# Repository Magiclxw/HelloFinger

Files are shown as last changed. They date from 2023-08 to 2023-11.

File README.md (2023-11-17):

# HelloFinger
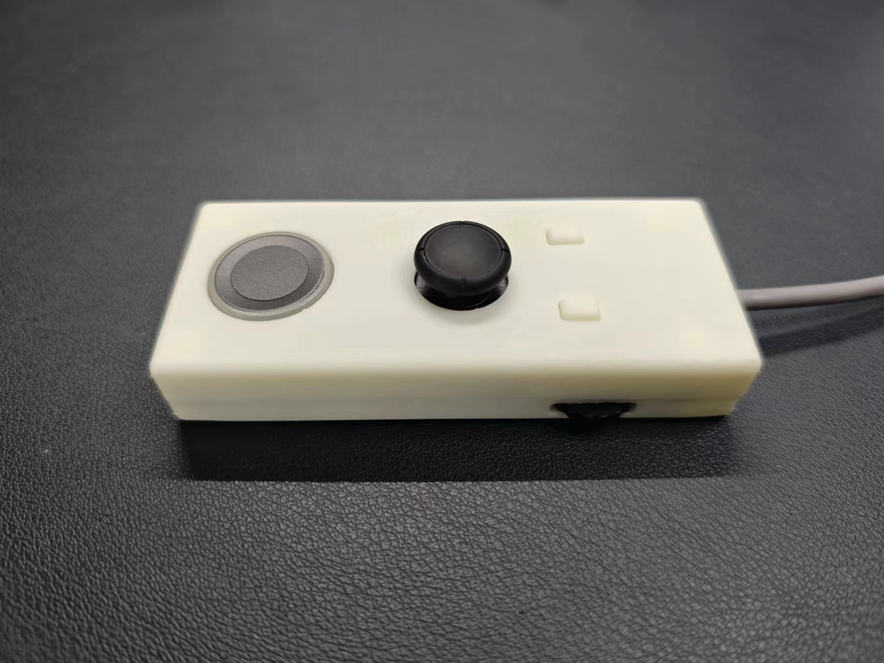
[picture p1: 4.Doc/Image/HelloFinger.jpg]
HelloFinger

## 关于本项目：
本项目通过操作单个模块，实现与Windows系统的HID通信，配合上位机实现电脑开机、电脑解锁、鼠标控制、快捷键、多任务、AI对话等功能。

## 项目相关功能：  
  1. AI 对话：接入通义千问API，可进行对话、问答；
  2. 一键开机：HelloFinger具有物理开机按键，按下按键即可实现电脑开机；
  3. 指纹解锁：无需输入密码，验证指纹即可实现电脑解锁；
  4. 自动输入账号密码：在需要输入账号密码的地方通过录入指纹即可自动输入和登录；
  5. 快捷键：可自定义配置快捷键，配置完成后录入指纹即可输入快捷键；
  6. 快捷启动多任务：可自由添加需要启动的程序，配置完成后录入指纹即可一键开启所有程序；
  7. 鼠标：HelloFinger具有鼠标左键、右键、滚轮的功能；
  8. Action：HelloFinger具有一个物理Action按键，用户可以自定义其功能；
  9. RGB灯效：HelloFinger具有6颗RGB灯，可以通过上位机配置其灯效；

## 开发平台：
-**外壳设计**：SolidWorks  
-**原理图、PCB设计**：立创eda  
-**固件开发**：Keil5  
-**上位机开发**：Qt  

## 设计原理
HelloFinger使用一颗STM32F103作为主控通过串口与CH9329芯片通信,CH9329通过HID接口与Windows系统交互；交互方式分为两类，一类直接操作Windows系统，一类以自定义数据包方式与Windows系统进行数据传输。上位机通过HID接口收发自定义数据包，进而实现自定义的交互功能。
在整个系统中，CH9329芯片作为处理器和上位机通信的桥梁，硬件外设产生的各种操作(如编码器拨动、摇杆移动、指纹识别验证等)经过处理后都会通过CH9329传输到电脑，同时，上位机的各种操作也会通过CH9329以指令的方式传输给处理器。

## 开发环境
  1. Qt
     1. 版本：V5.12.12
     2. 编译环境: MinGW 32-bit
     3. 链接库
        1. [全局鼠标键盘监听库](https://github.com/mahuifa/QtGlobalEvent)
        2. [HID通信库](https://github.com/libusb/hidapi)
  2. Keil 5
     1. 版本:5.26.2
     2. 编译器:5.06
     3. 软件包:Keil.STM32F1xx_DFP.2.1.0

## 目录结构
  1. Hardware:硬件文件夹，包含与PCB相关文件；
  2. Firmware:固件文件夹，包含STM32开发相关工程，**bootloader功能尚未实现**；
  3. Software:上位机文件夹，包含上位机工程及编译文件；
  4. Doc:文档文件夹，包含datasheet以及项目相关文档；
  5. Model:模型文件夹：包含3D打印文件；
  6. Tools：工具文件夹：包含硬件外设的测试工具；

## 原理图
  1. 连接器  
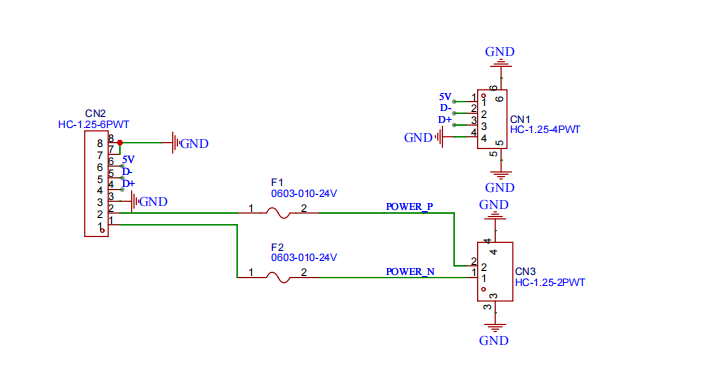
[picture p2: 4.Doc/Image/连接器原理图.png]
连接器
  
  2. 主板  
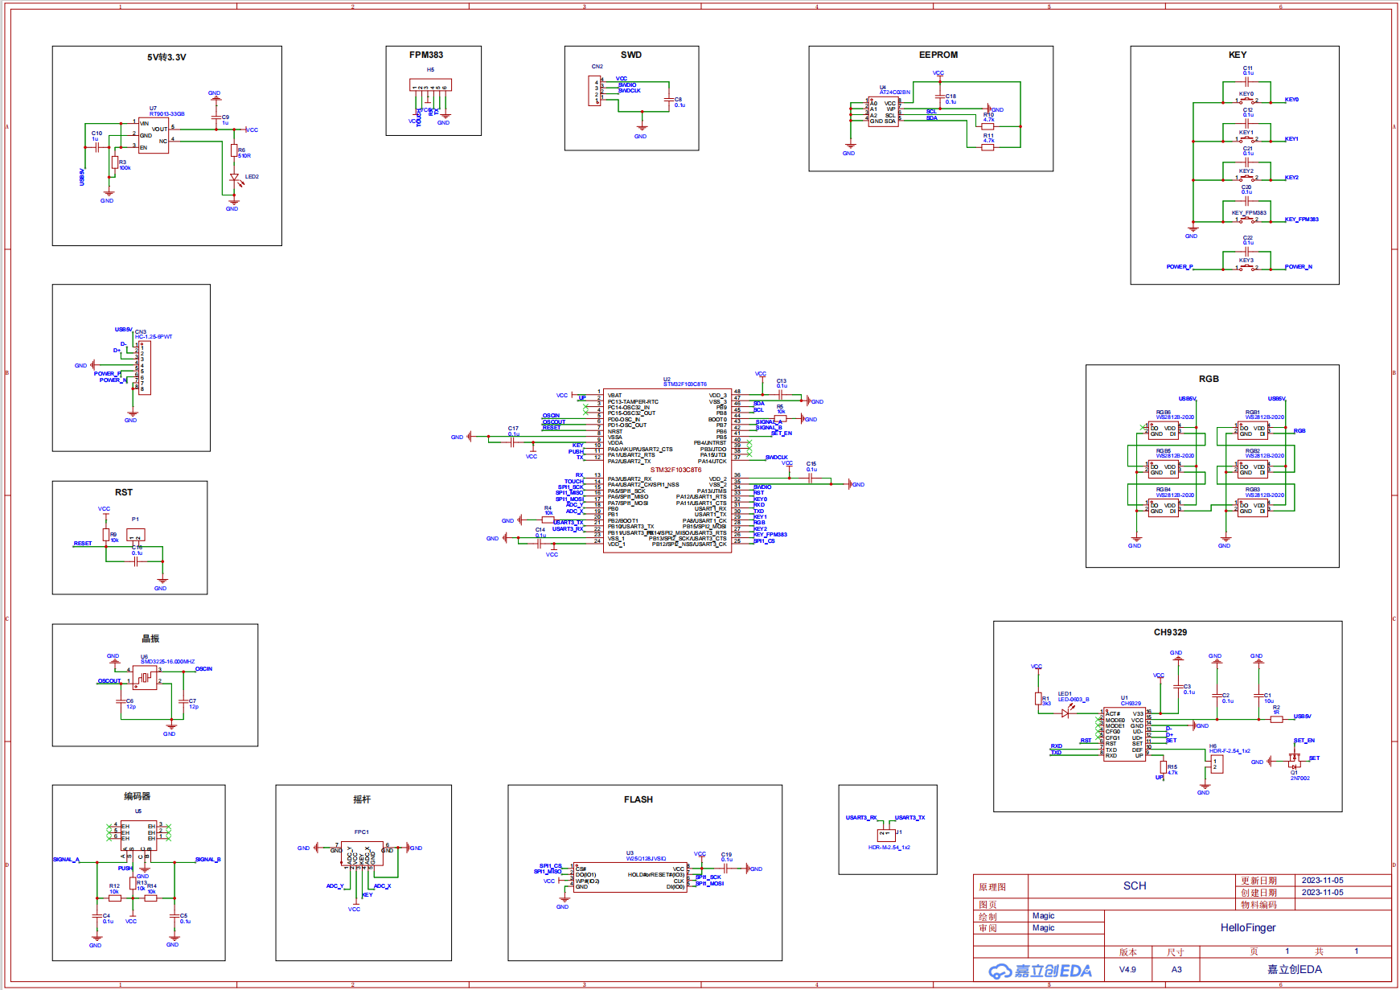
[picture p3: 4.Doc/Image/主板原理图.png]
主板
  

## PCB说明
本项目需要2个PCB板，分别是主板和连接器板，其中连接器板不是必须的，如果不需要连接电脑的物理开机键，就可以舍弃掉连接器板。
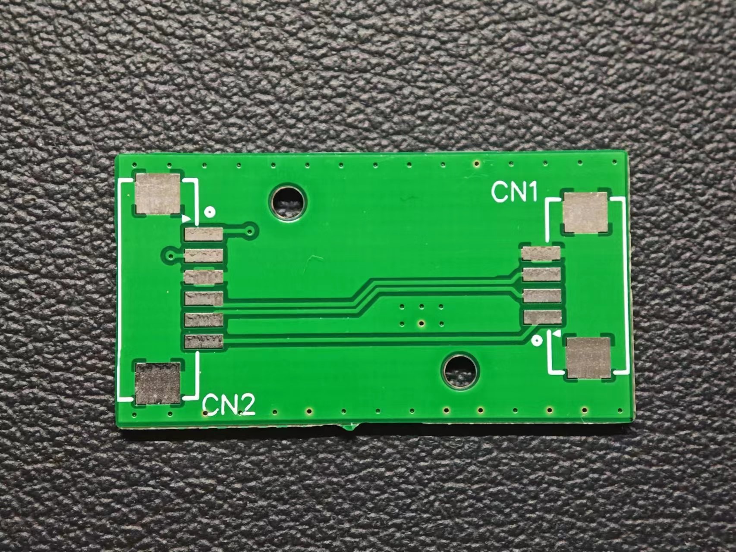
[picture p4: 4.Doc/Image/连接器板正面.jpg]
连接器板正面
  1. 连接器板正面
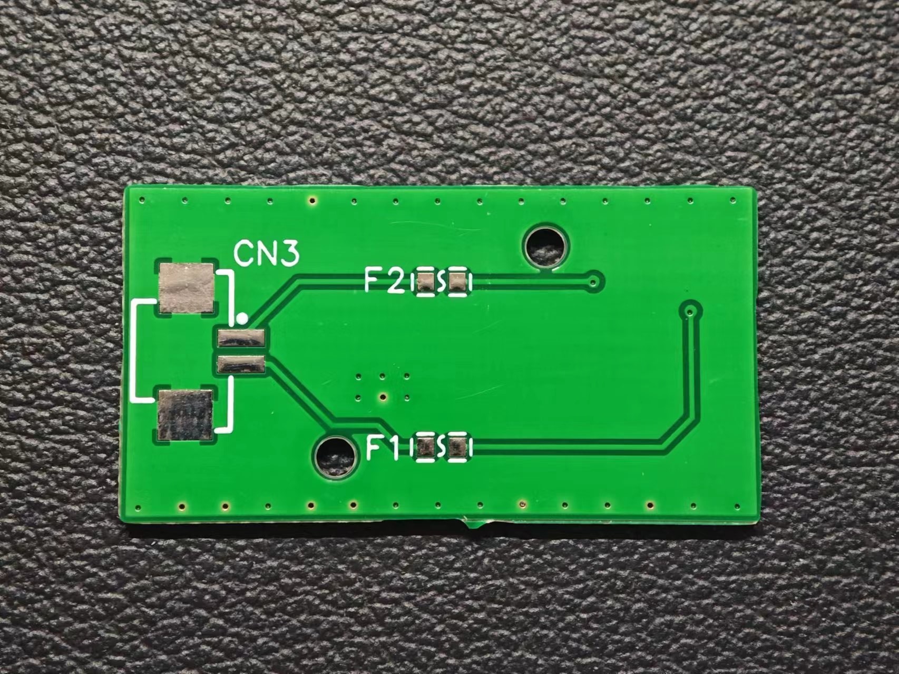
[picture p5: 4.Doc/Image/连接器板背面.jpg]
连接器板背面
  2. 连接器板背面
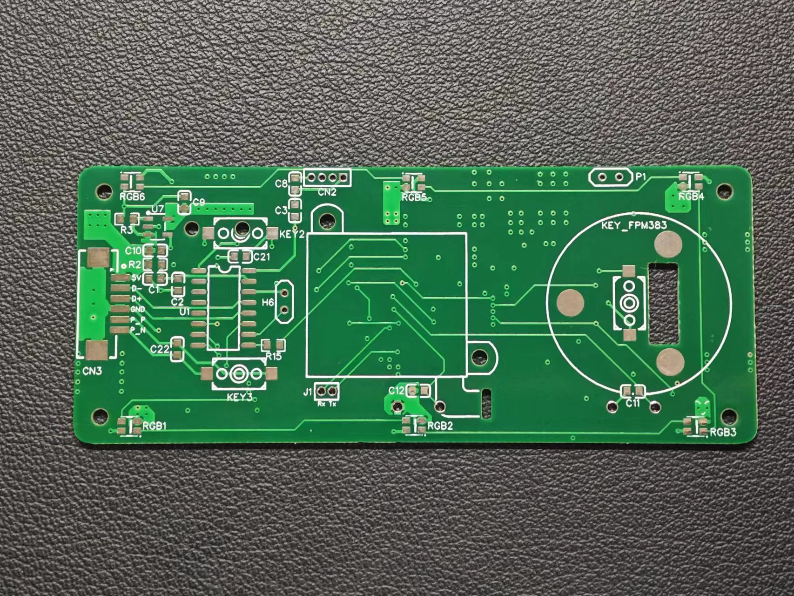
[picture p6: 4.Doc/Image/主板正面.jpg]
主板正面
  3. 主板正面
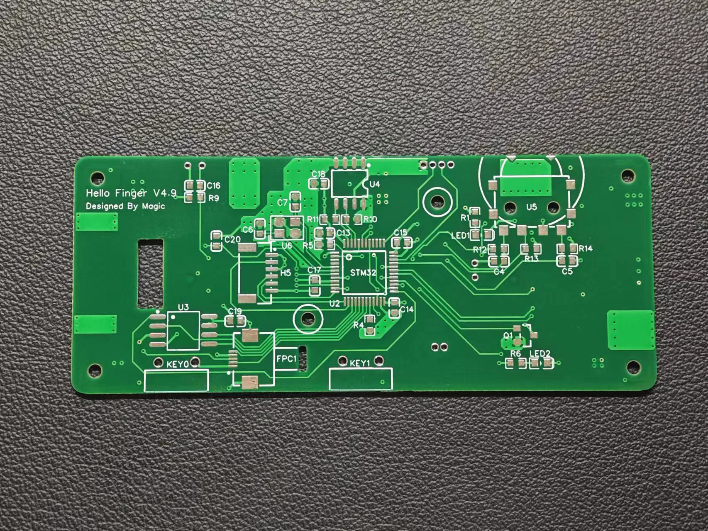
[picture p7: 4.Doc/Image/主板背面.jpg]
主板背面
  4. 主板背面
PCB采用4层板，电容电阻封装采用0603，整体含有3个非标准封装，分别是JoyStick摇杆、FPM383C指纹识别模块以及弯角微动。
PCB焊接时需要遵循一定的焊接步骤，具体的步骤见[焊接指南](https://github.com/Magiclxw/HelloFinger/blob/main/4.Doc/HelloFinger%E7%84%8A%E6%8E%A5%E6%8C%87%E5%8D%97V1.0.pdf)

## 3D结构件
HelloFinger一共有8个结构件，分别是[连接器上壳](https://github.com/Magiclxw/HelloFinger/blob/main/5.Model/%E8%BF%9E%E6%8E%A5%E5%99%A8%E4%B8%8A%E5%A3%B3..STL)、[连接器下壳](https://github.com/Magiclxw/HelloFinger/blob/main/5.Model/%E8%BF%9E%E6%8E%A5%E5%99%A8%E4%B8%8B%E5%A3%B3.STL)、[主板上壳](https://github.com/Magiclxw/HelloFinger/blob/main/5.Model/%E4%B8%8A%E5%A3%B3.STL)、[主板下壳](https://github.com/Magiclxw/HelloFinger/blob/main/5.Model/%E4%B8%8B%E5%A3%B3.STL)、[上按钮*2](https://github.com/Magiclxw/HelloFinger/blob/main/5.Model/%E4%B8%8A%E6%8C%89%E9%92%AE.STL)、[侧键*2](https://github.com/Magiclxw/HelloFinger/blob/main/5.Model/%E4%BE%A7%E9%94%AE.STL)。
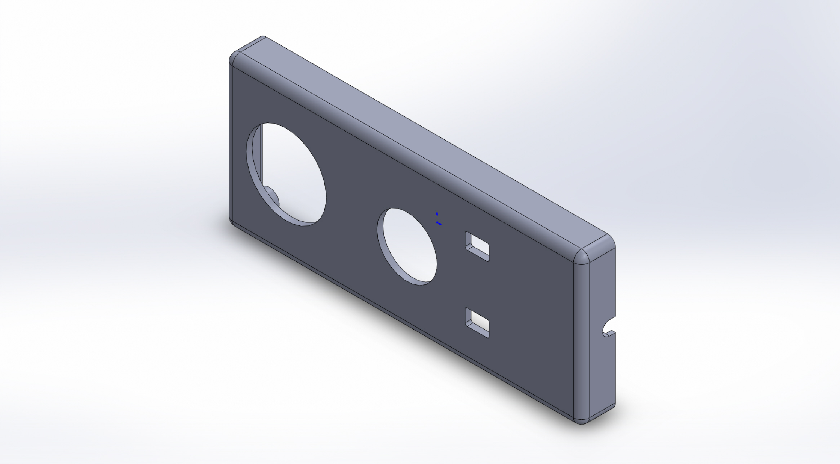
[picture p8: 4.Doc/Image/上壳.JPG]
上壳
  1. 上壳
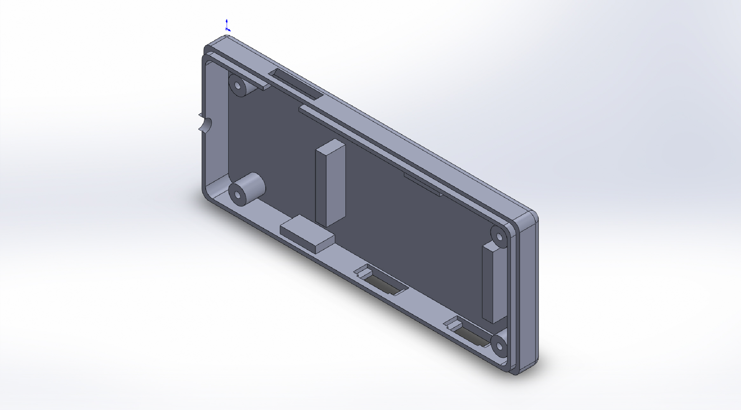
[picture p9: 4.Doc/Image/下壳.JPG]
下壳
  2. 下壳
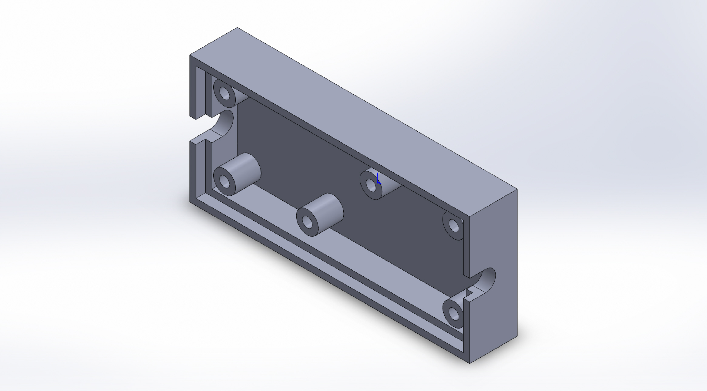
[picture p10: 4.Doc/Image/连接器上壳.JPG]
连接器上壳
  3. 连接器上壳
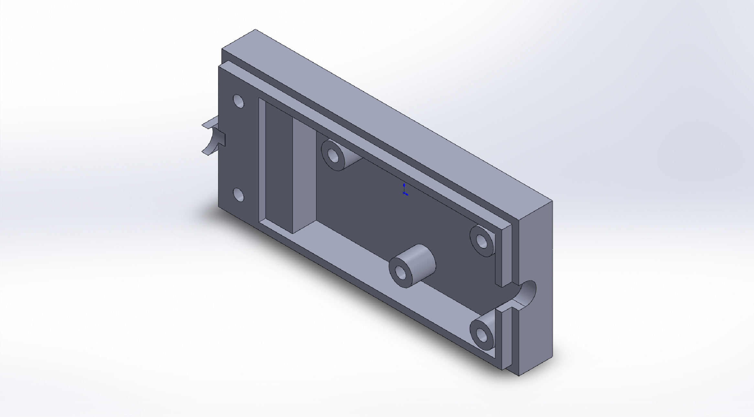
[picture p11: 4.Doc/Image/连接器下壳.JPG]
连接器下壳
  4. 连接器下壳
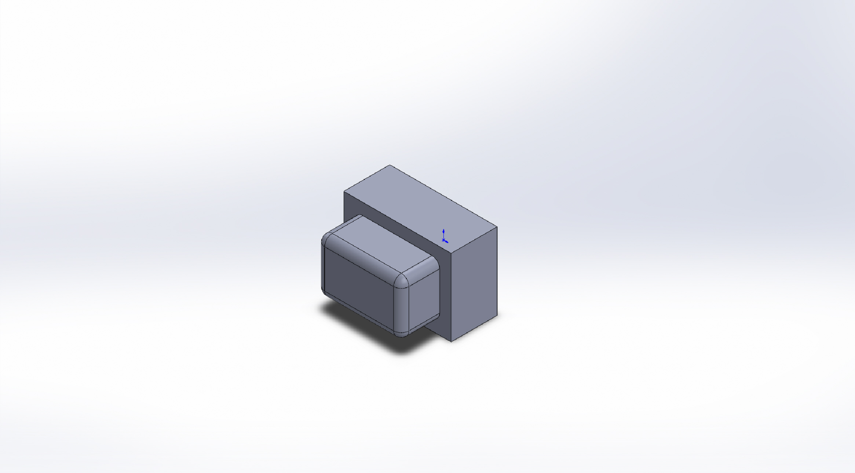
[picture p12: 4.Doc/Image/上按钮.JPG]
上按钮
  5. 上按钮
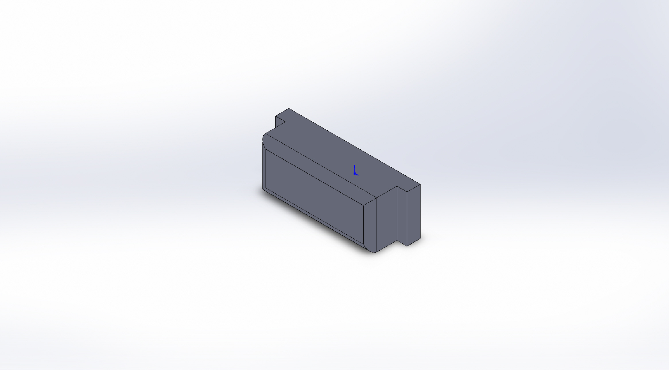
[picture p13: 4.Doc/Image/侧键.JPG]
侧键
  6. 侧键

##

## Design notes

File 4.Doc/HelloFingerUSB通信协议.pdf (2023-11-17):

# HelloFinger

## USB 通信协议

版本：V1.0 一 指令结构

下发指令：
协议传输模式下下传固 定头尾 | 1 byte | 1 byte | 2 byte | 2 byte | N byte | 1 byte | 固定校 验和
0x 57 | 0x AB | 0x 00 | 0x 87 | 0x 04 | 指 令 码 | 数 据 长度 | 指 令 类型 | 后 续 包 个 数 | 数据 | 校 验 和 | CHECKSU M

指令码：固定为 0xFE
数据长度：标识后续指令类型长度+数据部分长度(不包含校验和) 指令类型：标识指令功能
校验和：指令码-数据的累加和

上传指令：

二 指令描述

1、模式切换(保留)

方向：上位机→STM32
固定 头 | 指令 头 | 数据长 度 | 指令类 型 | 后续包个 数 | 模式 | 校验 和 | 固定校验 和
5 byte | 1 byte | 1 byte | 1 byte | 2 byte | 1 byte | 1 byte | 1 byte
协议传输模式下下传固定头尾 | byte 0 | byte 1 | byte 2 | byte 3 | byte n | byte n+1 | 固定 校验 和
0x57 | 0xAB | 0x00 | 0x87 | 0x04 | 指 令 码 | 数据 长度 | 指令 类型 | 执行 结果 | 数 据 | 校验 和

0xFE | 0x04 | 0x0000 | mode
mode：0x01：切换为透传模式
0x02：切换为协议传输模式

透传模式：CH9329 作为上位机和芯片之间的媒介，使上位机和芯片可以互相传 输数据
协议传输模式：CH9329 作为 HID 设备控制 PC，数据传输方向为上位机→芯片。

2、心跳包(保留)

方向：上位机→STM32

Sidebar:侧边栏状态 -0:隐藏 -1:显示

响应：

3、获取硬件信息

方向：上位机→STM32

响应：STM32→上位机

固定 头 | 指令 头 | 数据长 度 | 指令类 型 | 后续包个 数 | 侧边栏 状态 | 校验和 | 固定校验 和
5 byte | 1 byte | 1 byte | 1 byte | 2 byte | 1 byte | 1 byte | 1 byte
| 0xFE | 0x0 | 0x01 | 0x0000 | Sidebar | checksum
固定头 | 指令头 | 数据长度 | 指令类型 | 执行结果 | 校验和 | 固定校验和
5 byte | 1 byte | 1 byte | 1 byte | 1 byte | 1 byte | 1 byte
| 0xFE | 0x02 | 0x10 | | checksum
固定 头 | 指令 头 | 数据长 度 | 指令类 型 | 后续包个 数 | 校验和 | 固定校验 和
5 byte | 1 byte | 1 byte | 1 byte | 2 byte | 1 byte | 1 byte
| 0xFE | 0x0 | 0x03 | 0x0000 | checksum
固 定 头 | 指 令 头 | 数 据 长 度 | 指 令 类 型 | 执行 结果 | Flash id | CH9329 version | FPM383C SN | 校验和 | 固定校 验和
5 byte | 1 byte | 1 byte | 1 byte | 1 byte | 2 byte | 1 byte | 32 byte | 1 byte | 1 byte

4、获取索引表存储状态信息

方向：上位机→STM32

响应：STM32→上位机
固定 头 | 指令 头 | 数据长 度 | 指令类 型 | 执行结 果 | 数据 | 校验和 | 固定校验 和
5 byte | 1 byte | 1 byte | 1 byte | 1byte | 32 byte | 1 byte | 1 byte
| 0xFE | 0x22 | 0x10 | | 索引表信 息 | checksum

5、注册指纹

方向：上位机→STM32

参数说明：
id：id 号，高字节在前，低字节在后。例如录入 1 号指纹，则是
0001H。
times：录入次数：1byte，录入 2 次，则为 02H，录入 4 次则为
04H。
param：参数
1) bit0：采图背光灯控制位，0-LED 长亮，1-LED 获取图像成功后灭；
2) bit1：采图预处理控制位，0-关闭预处理，1-打开预处理；
3) bit2：注册过程中，是否要求模组在关键步骤，返回当前状态，0-要求返回，
1-不
要求返回；
4) bit3：是否允许覆盖 ID 号，0-不允许，1-允许；
5) bit4：允许指纹重复注册控制位，0-允许，1-不允许；
6) bit5：注册时，多次指纹采集过程中，是否要求手指离开才能进入下一次指纹 图
0xFE | 0x03 | 0x03 | checksum
固定头 | 指令头 | 数据长度 | 指令类型 | 后续包个数 | 校验和 | 固定校验和
5 byte | 1 byte | 1 byte | 1 byte | 2 byte | 1 byte | 1 byte
| 0xFE | 0x03 | 0x10 | 0x0000 | checksum
固定 头 | 指令 头 | 数据 长度 | 指令 类型 | 后 续 包 个数 | id 号 | 重复 次数 | 参数 | 校验和 | 固定 校验 和
5 byte | 1 byte | 1 byte | 1 byte | 2 byte | 2 byte | 1 byte | 2 byte | 1 byte | 1 byte
| 0xFE | 0x08 | 0x11 | 0x0000 | id | times | param | checksum

像采集， 0-要求离开；1-不要求离开；
7) bit6~bit15：预留。

响应：STM32→上位机
固定 头 | 指令 头 | 数据 长度 | 指令 类型 | 执行 结果 | 参数 1 | 参数 2 | 校验和 | 固定校 验和
5 byte | byte 0 | byte 1 | byte 2 | byte 3 | byte 4 | byte 5 | byte 6 | 1 byte
| 0xFE | 0x04 | 0x0B | | Param1 | Param2 | checksum

6、删除指纹

方向：上位机→STM32
固定 头 | 指令 头 | 数据 长度 | 命令 标志 | 后续包 个数 | 起始ID | 删除 个数 | 校验和 | 固定校验 和
5 byte | 1 byte | 1 byte | 1 byte | 2 byte | 2 byte | 1 byte | 1 byte | 1 byte
| 0xFE | 0x06 | 0x0C | 0x0000 | 0x00XX | 0x00XX | checksum

响应：STM32→上位机
固定头 | 指令码 | 数据长度 | 指令类型 | 执行结果 | 校验和 | 固定校验和
5 byte | byte 0 | byte 1 | byte 2 | byte 2 | byte 3 | 1 byte
| 0x14 | 0x01 | 0x0C | state | 0x??
state:
0x00:删除成功
0x01:删除失败

7、存储账号/密码/快捷键

功能：定义每个指纹所需要实现的功能。
方向：上位机→STM32
数据包 1:
固定头 | 包头 | 数据长度 | 指令标志 | 后续包个数 | 功能类型 | 指纹号
5 byte | 1 byte | 1 byte | 1 byte | 2 byte | 1 byte | 1 byte
| 0xFE | Data_length | 0x11 | PackageNum | Type | Index

续：

数据包 2：

数据包 3：

参数说明：
Data_length：数据长度 Data_length 之后到校验和(不含)之前的字节长度。
Type：功能类型
-0x00 开机密码
-0x01 密码
-0x02 账号+密码
-0x03 快捷键
-0x04 启动顺序
-0x05 开机密码（指纹+按键）
-0x06 密码（指纹+按键）
-0x07 账号+密码（指纹+按键）
-0x08 快捷键（指纹+按键）
-0x09 启动顺序（指纹+按键）

Index：指纹索引，该功能对应的指纹号。
Function_Len：功能的字节长度，当功能类型为开机密码或密码时，标识密码的
账号长度/密码长度/快捷键长度/快 捷启动序号 | 密码长度 | 校验和 | 固定校验和
1 byte | 1 byte | 1byte | 1 byte
Function_Len | Password_Len
固 定 头 | 包头 | 数据长 度 | 指令标 志 | 后续包个数 | 功能 类型 | 指纹 号 | 账号/ 密码/ 快捷 键值 | 校验 和 | 固定 校验 和
5 byt e | 1 byte | 1 byte | 1 byte | 2 byte | 1 byte | 1 byte | n byte | 1 byte | 1 byte
| 0xFE | Data_len gth | 0x11 | PackageNum -1 | Type | Index | | chec ksu m
固 定 头 | 包 头 | 数据长 度 | 指令标 志 | 后续包个 数 | 功能类 型 | 指纹 号 | 密码 值 | 校验 和 | 固定校 验和
5 byt e | 1 byte | 1 byte | 1 byte | 2 byte | 1 byte | 1 byte | n byte | 1byte | 1 byte
| 0xF E | Data_len gth | 0x11 | PackageN um-2 | Type | Index

长度；当功能类型为账号+密码时，标识账号的长度；当功能类型为快捷键时， 标识快捷键长度。
Function_Value：功能值，当功能类型为开机密码或密码时，标识密码值；当功 能类型为账号+密码时，标识账号值；当功能类型为快捷键时，标识快捷键值。 Password_Len：密码长度，当功能类型为账号+密码时，标识密码的长度。 Password_Value：密码值，当功能类型为账号+密码时，标识密码值。

8、设置指纹灯效

方向：上位机→STM32
固 定 头 | 包 头 | 数据 长度 | 命令 标志 | 后续包个数 | 功 能 码 | 起始 颜色 | 结束 颜色 | 循环 次数 | 校 验 和 | 固定校 验和
5 byte | byte 0 | byte 1 | byte 2 | 2 byte | byte 3 | byte 4 | byte 5 | byte 6 | byte 7 | 1 byte
| 0xFE | 0x05 | 0x0D | PackageNum | Func | Start color | End color | Cycle time

9、设置 RGB 呼吸等效

方向：上位机→STM32
固 定 头 | 包 头 | 数据 长度 | 指令 标志 | 后续包个数 | R | G | B | 间 隔 | 校 验 和 | 固定 校验 和
5 byte | 1 byte | 1 byte | 1 byte | 2 byte | 1 byte | 1 byte | 1 byte | 1 byte | byte 7 | 1 byte
| 0xFE | 0x05 | 0x12 | PackageNum

### 10、设置 Action 功能

方向：上位机→STM32
固定 头 | 包头 | 数据 长度 | 命令 标志 | 后续包个数 | 功能 类型 | 功能值 | 校验 和 | 固定 校验 和
5 byte | 1 byte | 1 byte | 1 byte | 2 byte | 1 byte | 4 byte | 1 byte | 1 byte

0xFE | 0x05 | 0x13 | PackageNum | Func | Func_value

参数说明：
Func：功能类型，标识按键属性
- 0x01：电源按键
- 0x02：多媒体按键
- 0x03：对话
Func_value：功能值，不同功能类型下的具体功能（当功能类型为电源按键 时，功能值第一 byte 有效）
电源按键：
- 0x0101：电源
- 0x0102：睡眠
- 0x0104：唤醒
多媒体按键：
- 0x02000001：KEY_MEDIA
- 0x02000002：KEY_EXPLORER
- 0x02000004：KEY_CALCULATOR
- 0x02000008：KEY_SCREEN_SAVE
- 0x02000010：KEY_MY_COMPUTER
- 0x02000020：KEY_MINIMIZE
- 0x02000040：KEY_RECORD
- 0x02000080：KEY_REWIND
- 0x02000100：KEY_EMAIL
- 0x02000200：KEY_WB_SEARCH
- 0x02000400：KEY_WB_FAVORITES
- 0x02000800：KEY_WB_HOME
- 0x02001000：KEY_WB_BACK
- 0x02002000：KEY_WB_FORWARD
- 0x02004000：KEY_WB_STOP
- 0x02008000：KEY_REFRESH
- 0x02010000：KEY_VOLUME_ADD
- 0x02020000：KEY_VOLUME_SUM
- 0x02040000：KEY_MUTE
- 0x02080000：KEY_PLAY_PAUSE
- 0x02100000：KEY_NEXT_TRACK
- 0x02200000：KEY_PREV_TRACK
- 0x02400000：KEY_CD_STOP
- 0x02800000：KEY_EJECT

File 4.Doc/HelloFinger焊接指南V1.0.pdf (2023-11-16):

# HelloFinger 焊接指南

## 版本：V1.0

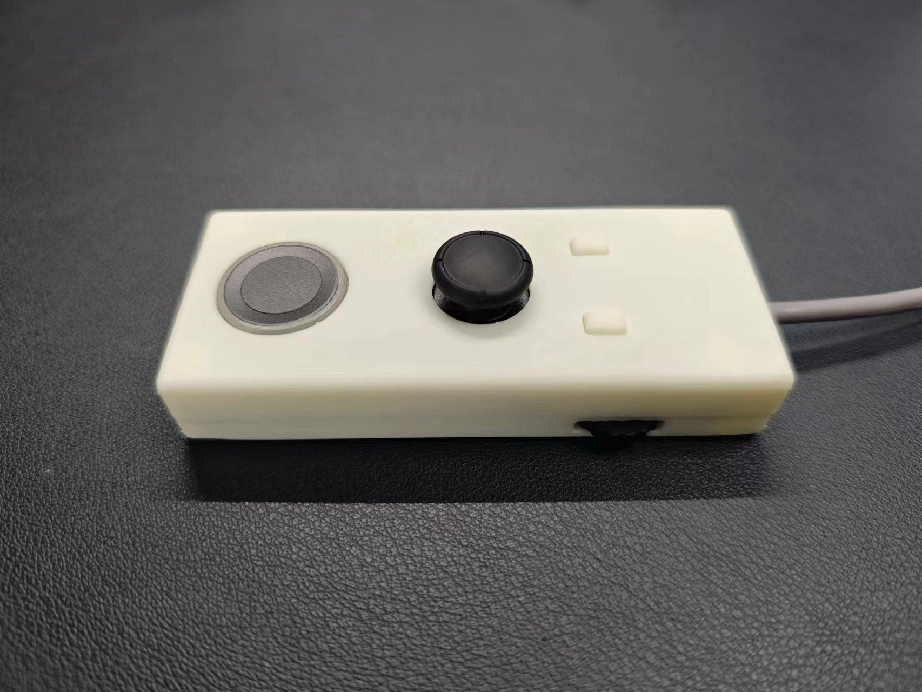
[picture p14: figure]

工具：烙铁、热风枪

焊接方式：手工焊接

焊接步骤：
1、背面首次焊接
1 | STM32 芯片焊接(烙铁)

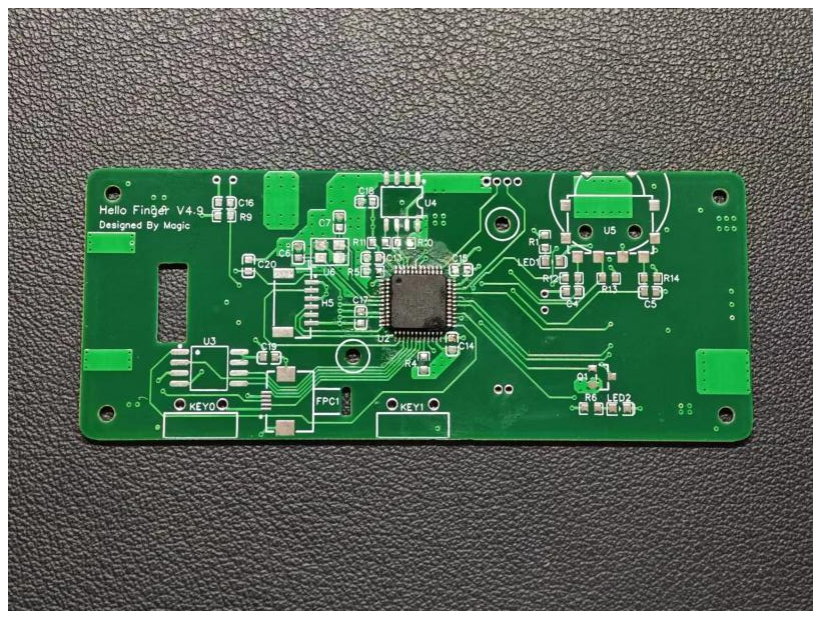
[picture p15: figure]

2 | 贴片器件焊接(热风枪)

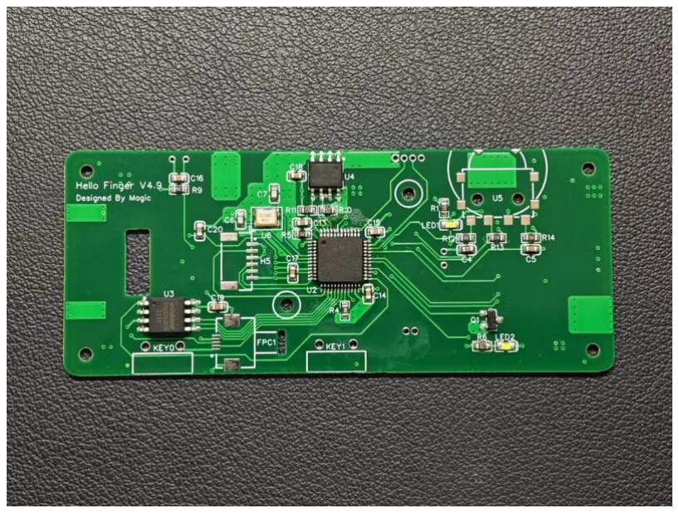
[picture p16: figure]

3 | FPC 连接器焊接(烙铁)
1) 把信号焊盘全部上锡，并将两侧的地焊盘涂上锡膏以便后续固定。
2) 将连接器引脚与焊盘对应，使用烙铁按压信号引脚使引脚与焊盘连
| 接。
3) 固定地焊盘：使用烙铁将锡线的锡与锡膏接触并保持几秒，使焊盘
| 上的锡膏导热后融化固定。
4) 信号引脚上锡：将锡膏涂在信号引脚上，使用烙铁加热以加固引脚。

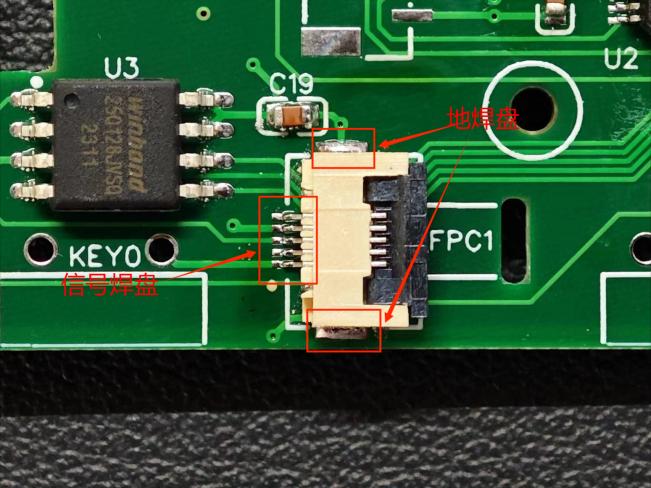
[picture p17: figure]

## 2 (可选)SH1.0 连接器焊接(烙铁) SH1.0 连接器可被导线直接焊接而替换掉。

2、正面焊接
1 贴片器件焊接(热风枪)
注意：此时不要焊接连接器、按键、rgb 灯这种含有塑料材质的元器件。

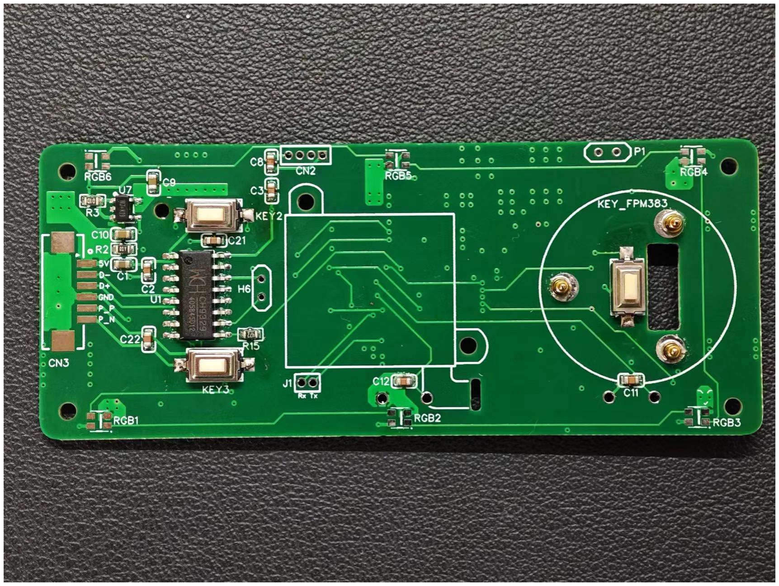
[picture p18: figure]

2 | 按键焊接(烙铁)
3 | RGB 灯焊接(烙铁)
| RGB 灯与焊盘的对应关系如下图所示，RGB 灯上绿色绿色线条对应 PCB
中间白线。

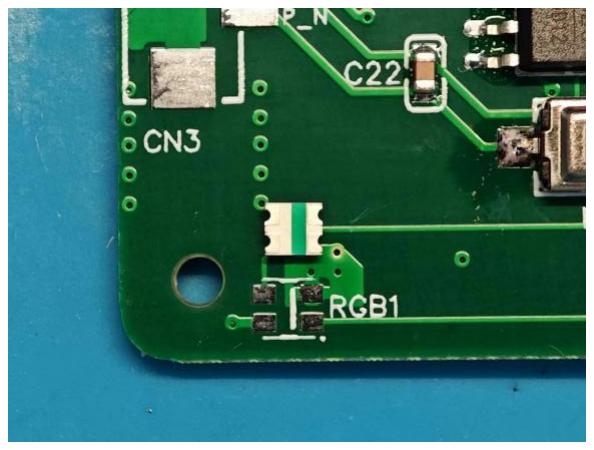
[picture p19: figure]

焊接 RGB 灯之前需要先把 RGB 灯的一个焊盘上锡，如下图所示。

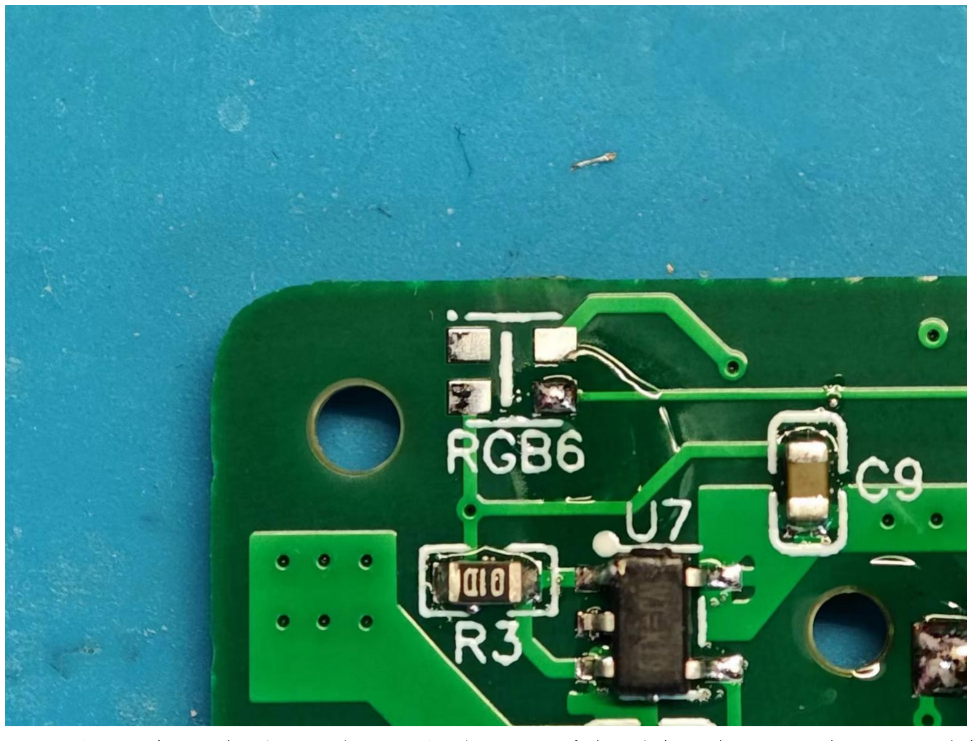
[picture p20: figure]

上锡以后将 RGB 灯在该焊点固定，接着将对角及其他焊点上锡。

4 | 排针焊接(烙铁)

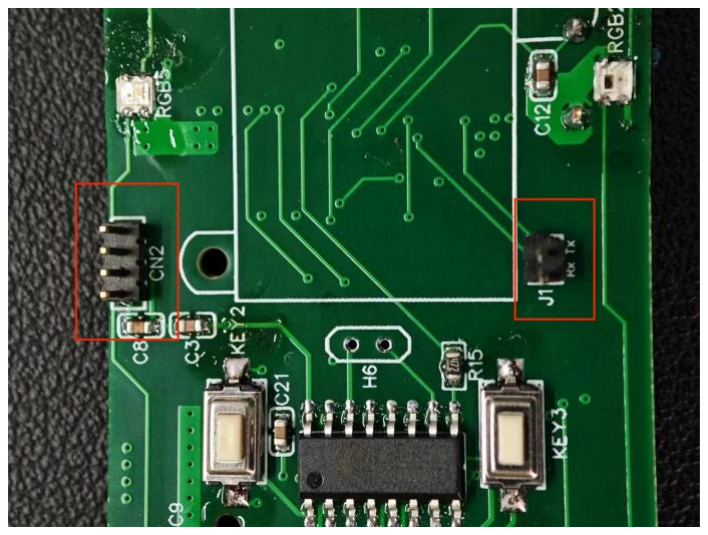
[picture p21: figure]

5 | (可选)HC 连接器焊接(烙铁) HC 连接器可被导线直接焊接而替换掉。

3、背面二次焊接
1 编码器焊接(烙铁(尖头))
编码器焊接之前需要把锡膏涂在所有焊盘上，接着放上编码器，使用尖头烙 铁将每个锡膏融化即可。

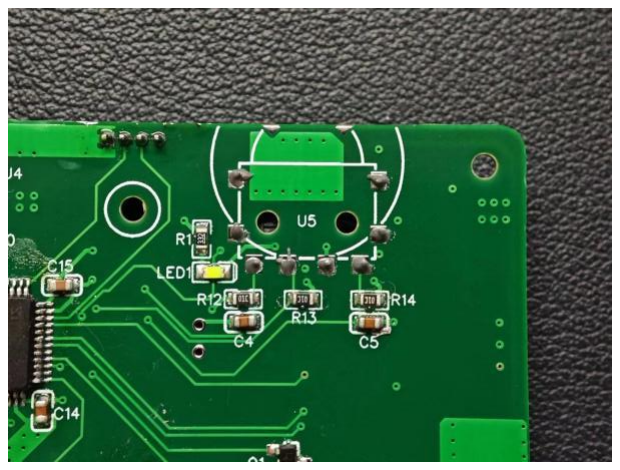
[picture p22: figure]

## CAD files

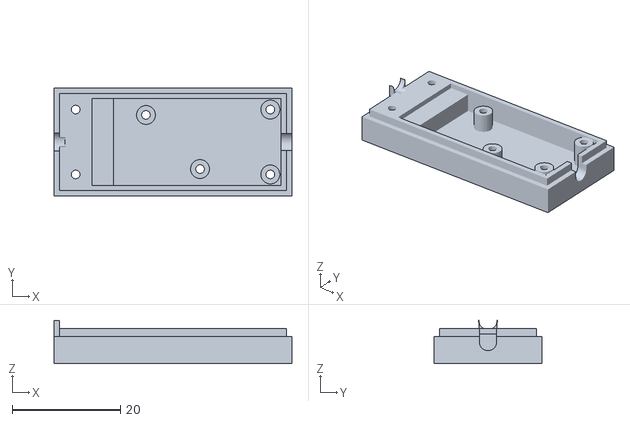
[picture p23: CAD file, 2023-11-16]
5.Model/连接器下壳.STL
44.0 x 20.0 x 8.00

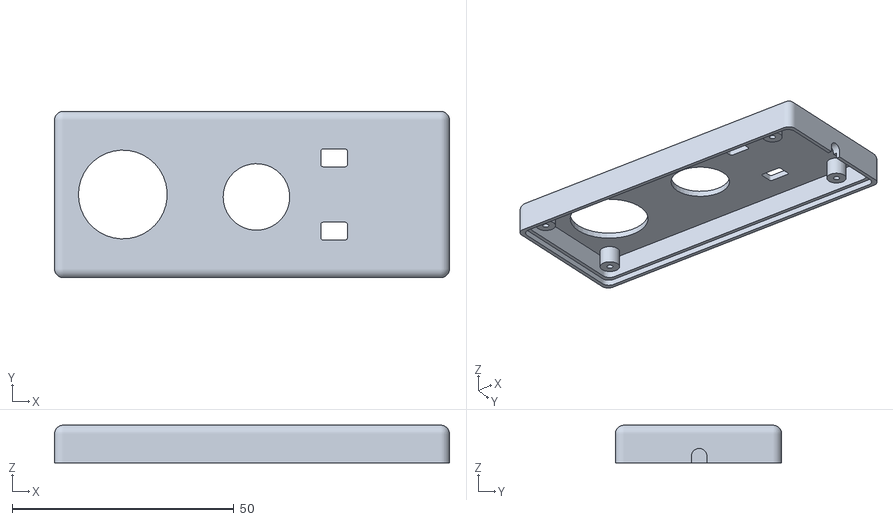
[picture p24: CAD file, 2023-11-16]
5.Model/上壳.STL
89.0 x 37.5 x 8.50

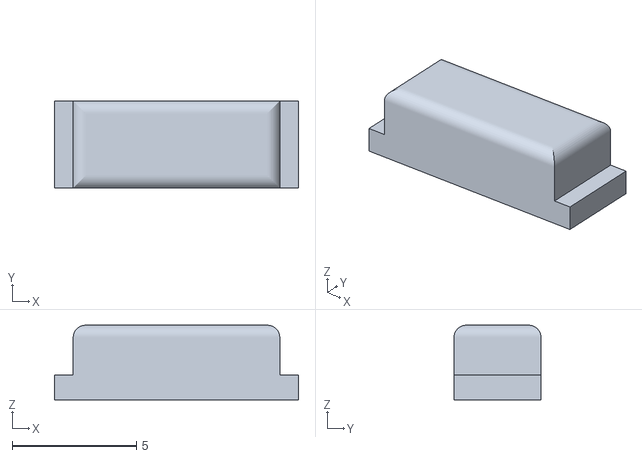
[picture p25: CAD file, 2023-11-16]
5.Model/侧键.STL
9.80 x 3.50 x 3.00

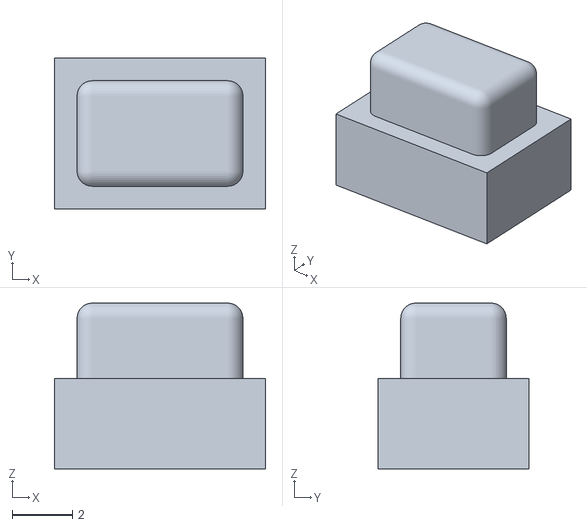
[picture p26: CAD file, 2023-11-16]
5.Model/上按钮.STL
7.00 x 5.00 x 5.50

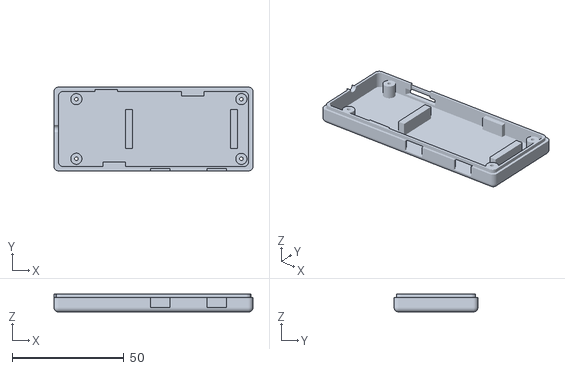
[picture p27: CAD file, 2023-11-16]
5.Model/下壳.STL
89.0 x 37.5 x 8.00

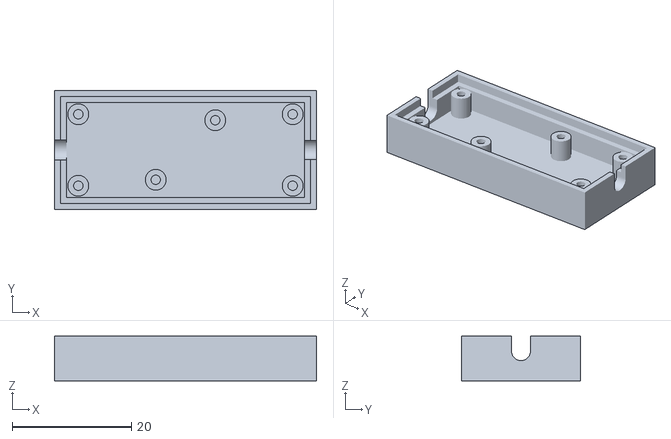
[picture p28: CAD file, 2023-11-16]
5.Model/连接器上壳..STL
44.0 x 20.0 x 7.50

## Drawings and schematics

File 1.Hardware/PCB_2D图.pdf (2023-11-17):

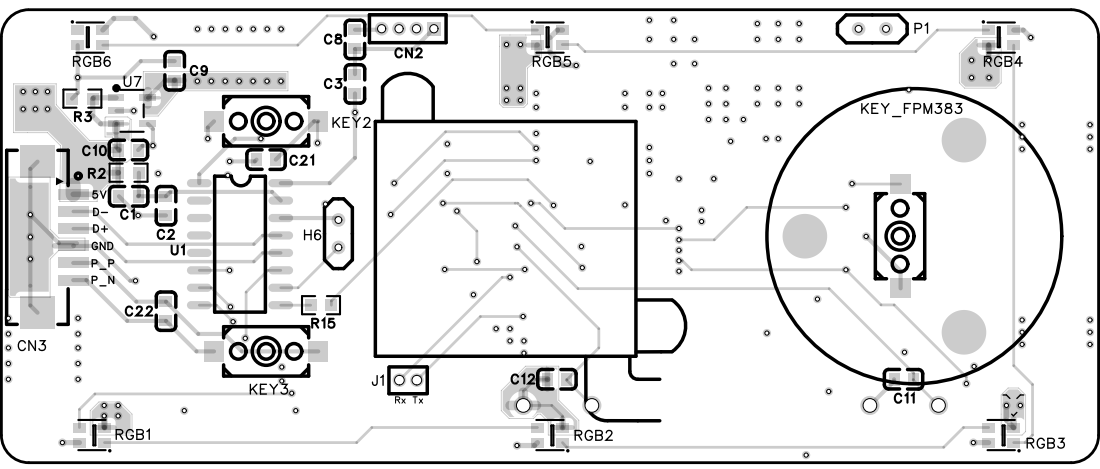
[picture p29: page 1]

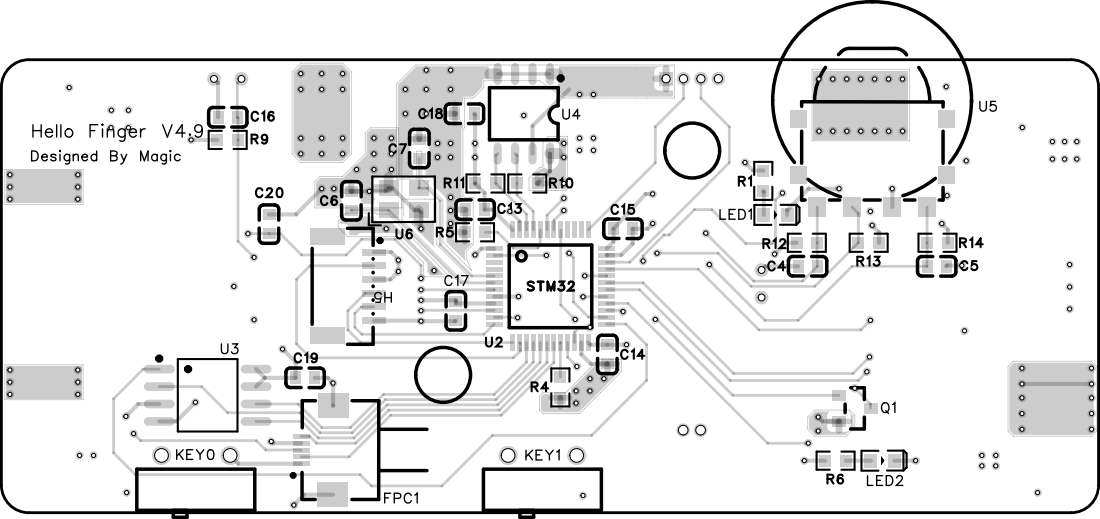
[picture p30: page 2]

Hello Finger V4.9 Designed By Magic

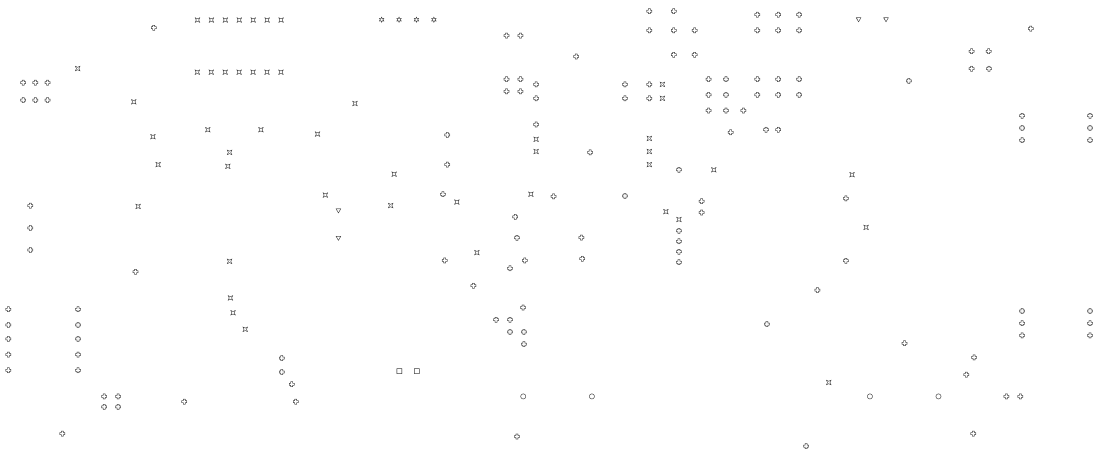
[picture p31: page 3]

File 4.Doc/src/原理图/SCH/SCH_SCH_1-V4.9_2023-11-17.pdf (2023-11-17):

# KEY

5V转3.3V | FPM383 | SWD | EEPROM

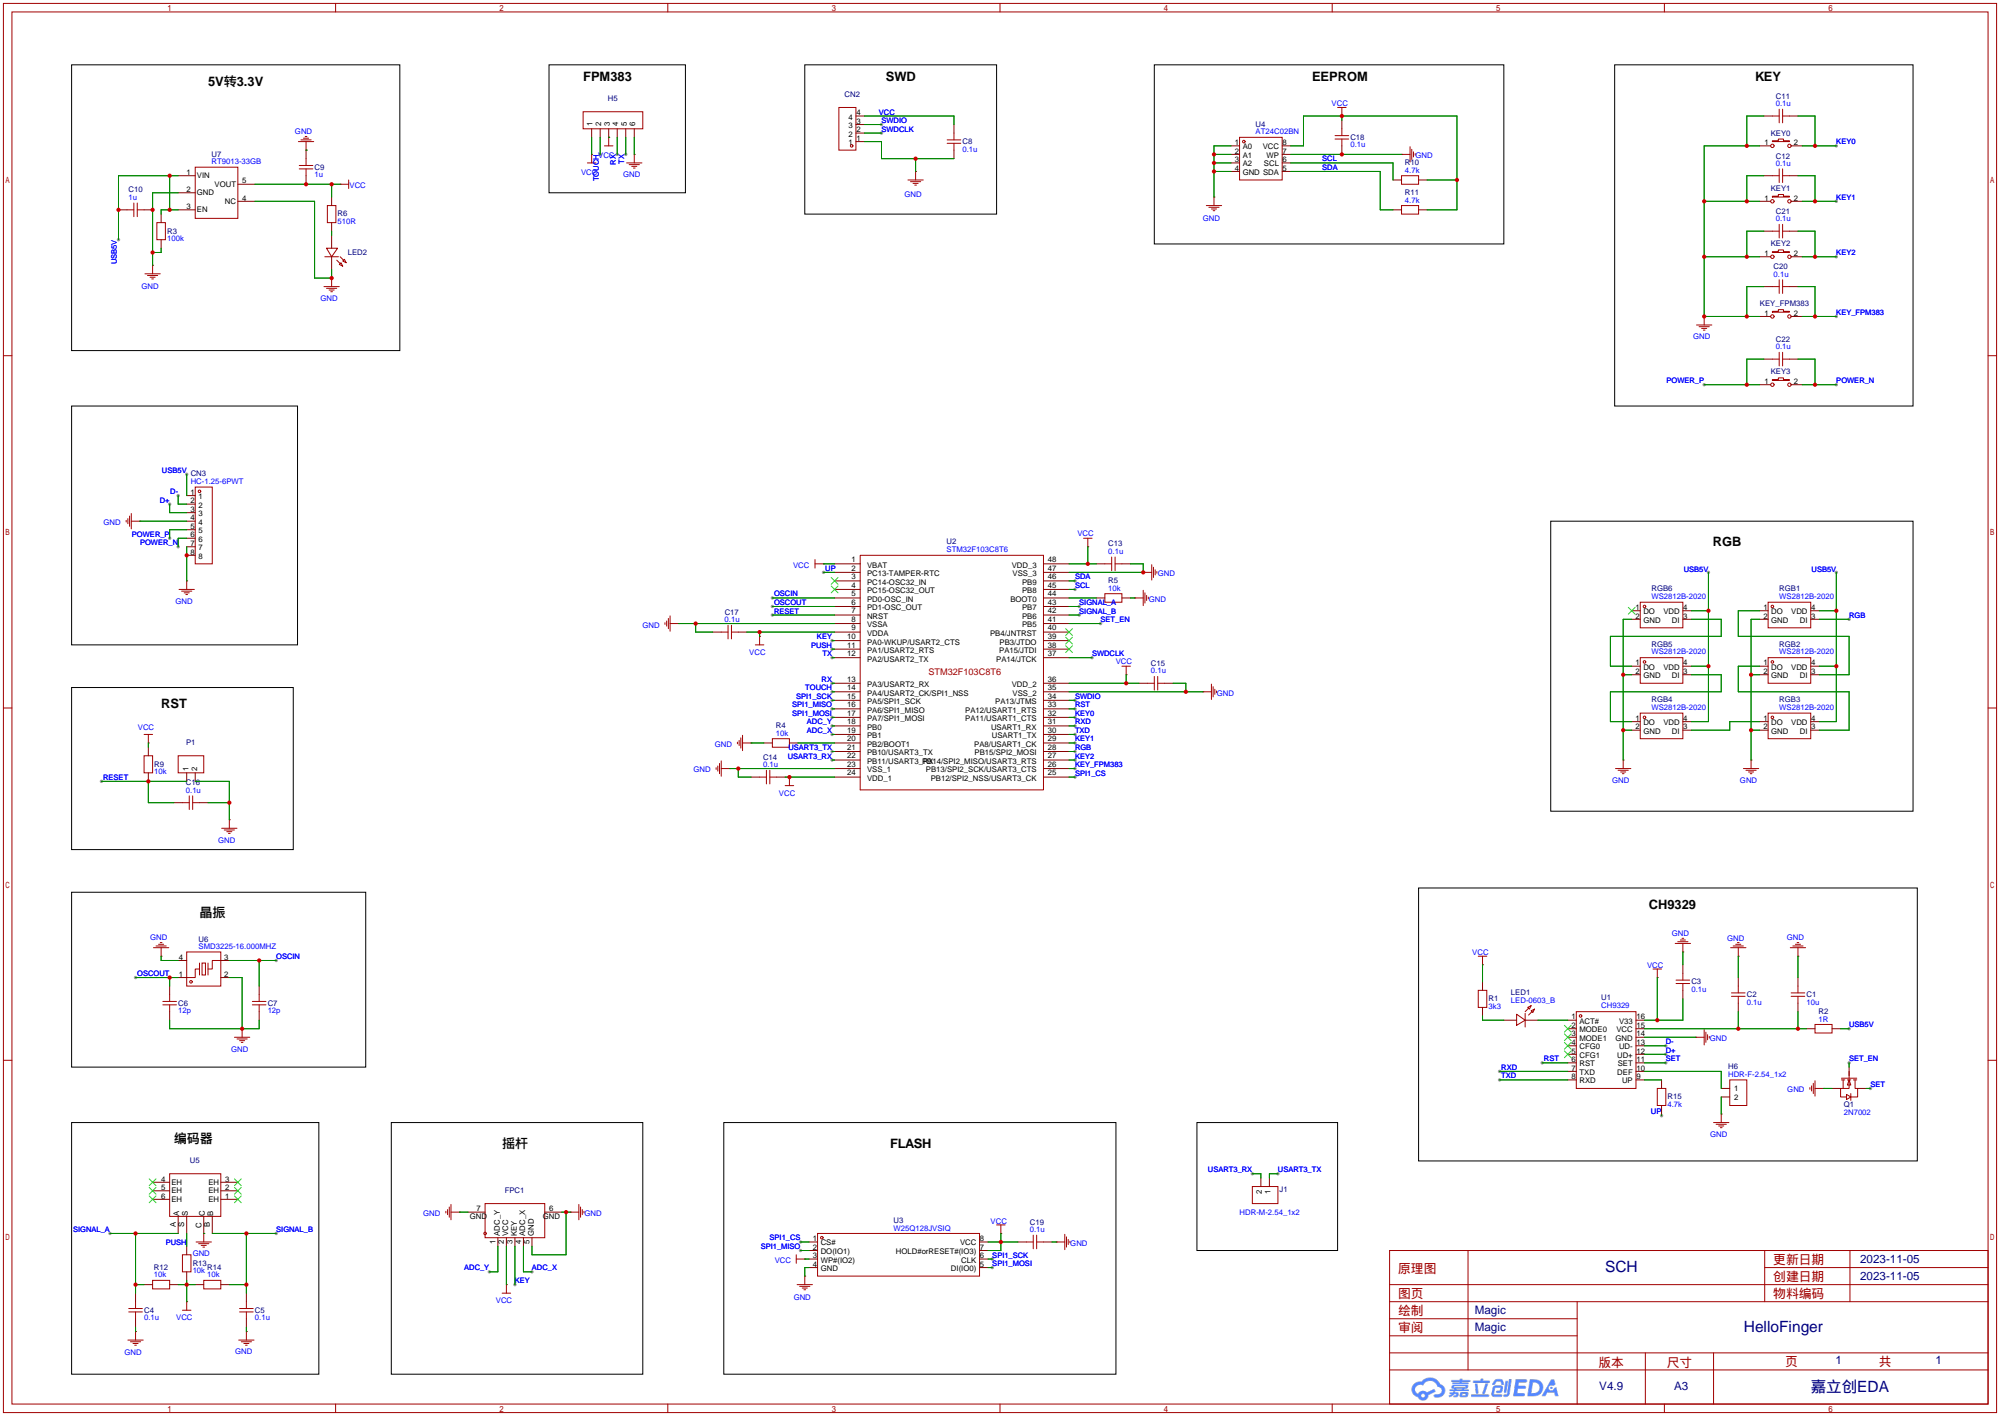
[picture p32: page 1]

PA14/JTCK 37 PA15/JTDI 38 PB3/JTDO 39 PB4/JNTRST 40 PB5 41 PB6 42 PB7 43 BOOT0 44 PB8 45 PB9 46 VSS_3 47 VDD_3 48

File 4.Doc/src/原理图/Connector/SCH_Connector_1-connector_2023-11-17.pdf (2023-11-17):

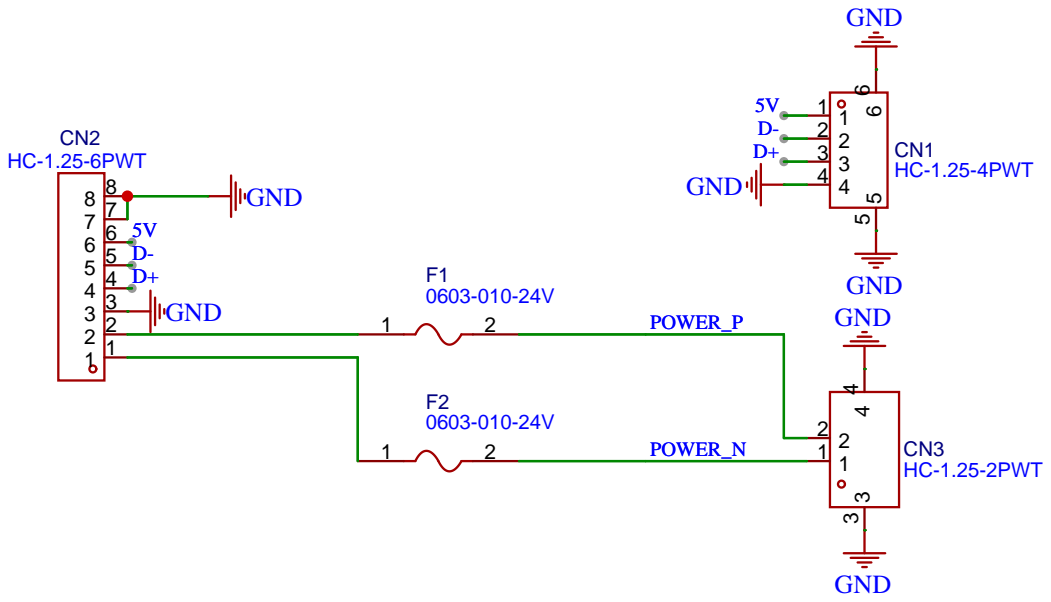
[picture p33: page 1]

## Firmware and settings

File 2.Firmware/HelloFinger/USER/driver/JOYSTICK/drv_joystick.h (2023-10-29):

#ifndef __DRV_JOYSTICK_H
#define __DRV_JOYSTICK_H

#include "sys_config.h"

typedef int(*FUNC_ADCRECVTCB)(uint8_t *pData, uint8_t Datasize);

extern ADC_HandleTypeDef hadc1;

extern uint16_t value_X_Y[2];

#define MIN_OFFSET 36
#define MAX_OFFSET 44

/* 默认看门狗临界值 */
#define DEFAULT_HIGH_THRESHOLD	2200
#define DEFAULT_LOW_THRESHOLD		1900

void MX_ADC1_Init(void);
int RegisterADC1ReceiveCallBack(FUNC_USARTRECVTCB ADC1READYVCBT);



#endif

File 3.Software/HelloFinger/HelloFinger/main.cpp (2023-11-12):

#include "form_mainwindow.h"
#include "form_entrance.h"
#include <QApplication>
#include <QSettings>
#include "interface.h"
#include <QDir>

int main(int argc, char *argv[])
{
    QApplication a(argc, argv);
    //Frame_MainWindow w;
    //w.show();
    Form_Entrance entrance;

    /* 设置开机自启动 */
    QSettings settings("HKEY_LOCAL_MACHINE\\SOFTWARE\\Microsoft\\Windows\\CurrentVersion\\Run", QSettings::NativeFormat);
    settings.setValue("HelloFinger", QCoreApplication::applicationFilePath());

    QDir dir;
    if (!dir.exists("config")) {
        dir.mkdir("config");
    }
    //entrance.show();

    return a.exec();
}

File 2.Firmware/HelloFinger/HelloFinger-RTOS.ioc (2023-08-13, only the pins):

Mcu.UserName=STM32F103C8Tx
PA10.Signal=USART1_RX
PA13.Signal=SYS_JTMS-SWDIO
PA14.Signal=SYS_JTCK-SWCLK
PA2.Signal=USART2_TX
PA3.Signal=USART2_RX
PA9.Signal=USART1_TX
PD0-OSC_IN.Signal=RCC_OSC_IN
PD1-OSC_OUT.Signal=RCC_OSC_OUT

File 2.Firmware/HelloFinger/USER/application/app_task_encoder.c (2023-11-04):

#include "app_task_encoder.h"
#include "drv_ch9329.h"

TaskHandle_t Task_Encoder_Handle = NULL;
TimerHandle_t Sidebar_Timer_Handler;

static void vTaskEncoderProcessing(void);
void Sidebar_TimerCallback(TimerHandle_t xTimer);

int ENCODER_NotifyFromISR(uint32_t dir)	//编码器任务通知
{
	portBASE_TYPE xHigherPriorityTaskWoken = pdTRUE;
	if(Task_Encoder_Handle != NULL)
	{
		xTaskNotifyFromISR((TaskHandle_t)Task_Encoder_Handle,dir,eSetValueWithOverwrite,&xHigherPriorityTaskWoken);
		portYIELD_FROM_ISR(xHigherPriorityTaskWoken);
	}
	return OPERATE_SUCCESS;
}

int Task_Encoder_CTLCreate(void)	//编码器任务创建
{
	xTaskCreate( (TaskFunction_t)vTaskEncoderProcessing,
								(const char*  )"Encoder",
								(uint32_t     )TASK_ENCODER_CONTROL_SIZE,
								(void *				)NULL,
								(UBaseType_t  )TASK_ENCODER_CONTROL_PRIORITY,
								&Task_Encoder_Handle);
	return OPERATE_SUCCESS;
}

__IO uint8_t timerFlag = 0;

static void vTaskEncoderProcessing(void)
{
	Sidebar_Timer_Handler = xTimerCreate((const char*  )"SidebarTimer",                 /* 定时器名 */
                                 (TickType_t    )5000,                      /* 定时器超时时间 */
                                 (UBaseType_t   )pdFALSE,                   /* 单次定时器 */
                                 (void*         )1,                         /* 定时器ID */
                                 (TimerCallbackFunction_t)Sidebar_TimerCallback);  /* 定时器回调函数 */
	uint32_t encoderState = 0;
	while(1)
	{
		encoderState = ulTaskNotifyTake((BaseType_t)pdTRUE,(TickType_t)portMAX_DELAY);
		if(timerFlag == 0)
		{
			if(encoderState == 0)
			{
				CH9329_REL_Mouse_Ctrl(0x01,0,0,button_NULL);
			}
			else
			{
				CH9329_REL_Mouse_Ctrl(0xFF,0,0,button_NULL);
			}
		}
		else if(timerFlag == 1)	//侧边栏弹出
		{
			if(encoderState == 0)
			{
				CH9329_Input_Fuc_Key(R_ALT|R_SHIFT|R_CTRL,KEY_LeftArrow);
				xTimerReset(Sidebar_Timer_Handler,(TickType_t)portMAX_DELAY);
				xTimerStart((TimerHandle_t  )Sidebar_Timer_Handler,(TickType_t)portMAX_DELAY);
			}
			else
			{
				CH9329_Input_Fuc_Key(R_ALT|R_SHIFT|R_CTRL,KEY_RightArrow);
				xTimerReset(Sidebar_Timer_Handler,(TickType_t)portMAX_DELAY);
				xTimerStart((TimerHandle_t  )Sidebar_Timer_Handler,(TickType_t)portMAX_DELAY);
			}
		}
			
	}
}

void Sidebar_TimerCallback(TimerHandle_t xTimer)
{
	timerFlag = 0;
}

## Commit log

2022-11-19 add USB通信协议.docx
2022-11-27 实现stm32串口1协议通信
2022-11-28 添加QT透传与协议传输转换相关逻辑(未验证)
2022-11-30 完善设备插入拔出逻辑，增加稳定性
2022-12-04 stm32固件添加通用注册指纹流程（未验证）
    [11288-20210531.csv, 11288-20210601.csv, 120-20210602.csv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]
2022-12-08 完善注册指纹流程
    [W800_160-20221206.csv, W800_160-20221208.csv]
2022-12-10 优化自动注册、自动验证
    [W800_160-20221210.csv]
2022-12-28 实现索引表状态传输
2023-01-01 添加qt指纹注册功能
2023-01-02 添加qt删除指纹功能
2023-02-11 qt完善
2023-02-12 实现ini格式和json格式读写
2023-02-19 V2.0代码小改(验证ch9329配置功能，set脚拉低失败)
2023-03-18 32固件新建
    [EEPROM存储定义.xls]
2023-03-20 新32获取索引表实现
2023-03-26 逻辑优化
2023-03-30 实现编码器功能
2023-04-02 add joystick driver
2023-04-05 实现编码器控制
2023-04-29 修改串口dma前备份
    [EEPROM存储定义.xls]
2023-05-03 透传改协议传输前备份
2023-05-05 透传改协议传输修改
    [EEPROM存储定义.xls]
2023-05-17 添加bootloader工程(未实现),实现qt颜色选择功能
2023-05-28 qt 添加开机密码发送功能
    [EEPROM存储定义.xls]
2023-06-21 添加ws2812驱动前备份
    [EEPROM存储定义.xls]
2023-08-19 实现joystick
2023-08-21 spi_dma create
    [上壳.SLDPRT, 下壳.SLDPRT, 按键.SLDPRT]
2023-09-09 实现指纹注册
2023-09-10 实现指纹验证功能
    [FLASH地址定义.xls]
2023-09-16 实现指纹解锁功能
    [FLASH地址定义.xls]
2023-09-16 实现spi-dma传输
2023-09-19 实现账号+密码解锁方式
    [FLASH地址定义.xls]
2023-09-21 实现rgb呼吸灯效
2023-09-23 修复rgb bug
2023-09-23 优化结构
    [11288-20210531.csv, 11288-20210601.csv, 120-20210602.csv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]
2023-09-30 9.30:常规跟新(FPM383F添加指纹功能存在问题)
2023-10-02 qt 实现快捷键格式转换
2023-10-04 qt 实现快捷启动文件读写
2023-10-06 10.6备份
2023-10-14 实现快捷启动功能
    [FLASH地址定义.xls]
2023-10-15 侧边栏功能完善
2023-10-21 20231021: feat:导入通义千问api
    [FLASH地址定义.xls]
2023-10-22 20232022: 1、适配V4.8(iic与编码器引脚调换); 2、添加普通按键控制逻辑
2023-10-23 20231023: 1、fpm383c驱动优化； 2、Action功能实现；
2023-10-24 20231024:底层优化
2023-10-31 20231030:添加指纹模块灯效控制
    [EEPROM存储定义.xls]
2023-11-04 20231104:添加侧边栏控制逻辑
    [V4.6侧键.SLDPRT, 上壳.SLDPRT, 上按钮.SLDPRT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]
2023-11-06 20231106:添加上位机代码注释
2023-11-09 20231109:工程整理
    [连接器下壳.SLDPRT]
2023-11-12 20231112:实现上位机获取固件、硬件信息
    [11288-20210531.csv, 11288-20210601.csv, 120-20210602.csv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]
2023-11-17 20231117:警告代码删除
    [11288-20210531.csv, 11288-20210601.csv, 120-20210602.csv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]
2023-11-17 20231117:添加pcb图片
2023-11-17 20231117:添加外壳图片
2023-11-17 20231117:添加原理图、Gerber
    [EEPROM存储定义.xls]
2023-11-17 20231117:原理图添加
